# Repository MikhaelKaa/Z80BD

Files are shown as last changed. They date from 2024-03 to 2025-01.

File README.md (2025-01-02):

# Z80BD

## Описание

Этот проект представляет собой комплексное решение для аппаратной и программной отладки ZX Spectrum совместимых компьютеров. 

Первая версия прототипа собранного в январе 2024 года:

[{#Первый прототип}](/Proto_on_socket/README.md)

Текущая версия:

[{#Второй прототип}](/Proto_on_slot/)

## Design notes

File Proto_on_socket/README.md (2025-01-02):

# Z80BD

## Описание

Этот проект представляет собой комплексное решение для аппаратной и программной отладки компьютеров серии ZX Pentagon. Он включает в себя устройство для подмены ПЗУ микросхемой статической памяти, программатор на базе STM32 для удобной загрузки и выгрузки кода, а также дополнительные функции для расширения возможностей стандартного ZX Pentagon.

## Особенности

- **Подмена ПЗУ:** Устройство позволяет заменить стандартное ПЗУ на микросхему статической памяти, что облегчает процесс отладки и разработки.
- **Программатор STM32:** Встроенный программатор на базе STM32 обеспечивает простую загрузку и выгрузку кода, а также SRAM, что делает процесс разработки более гибким и доступным.
- **Чтение порта 0x7ffd:** Устройство расширяет возможности стандартного ZX Pentagon, добавляя функционал чтения порта 0x7ffd.
- **Совместимость с КЕШ-доработкой:** Устройство совместимо с популярной доработкой типа КЕШ, что позволяет использовать уже написанные для этого софты. Объем кеш памяти - 32768 байт.

## Начало работы

Для начала работы с устройством необходимо выполнить следующие шаги:

1. **Сборка устройства:** Следуйте инструкциям по сборке, предоставленным в разделе [Сборка устройства](#сборка-устройства).
2. **Прошивка программатора:** Загрузите последнюю версию прошивки для STM32, используя предоставленные инструменты.
3. **Подключение к ZX Pentagon:** Подключите устройство к ZX Pentagon согласно схеме подключения.
4. **Загрузка ПО:** Используйте программатор для загрузки необходимого ПО в статическую память.

## Сборка устройства

На данный момент сделан прототип.
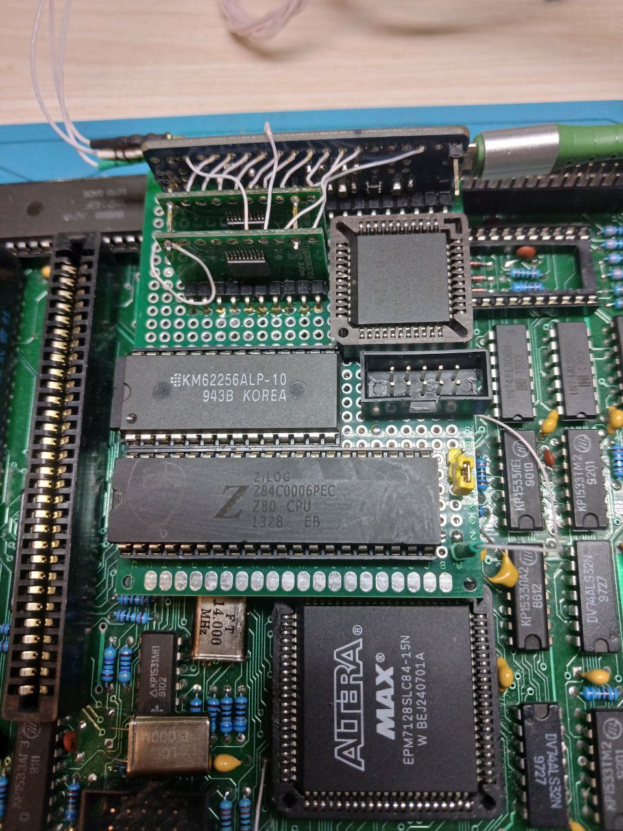
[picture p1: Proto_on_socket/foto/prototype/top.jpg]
top Установлен в PENTAGON-1024SL ver 2.2

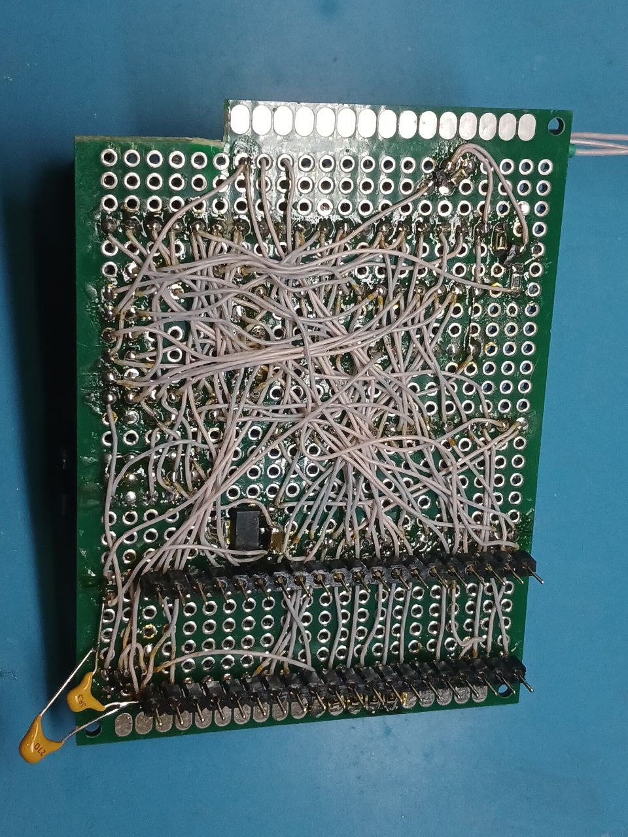
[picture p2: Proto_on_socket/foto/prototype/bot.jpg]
top Монтаж МГТФ


## Программное обеспечение

Програмное обеспечение находиться в стадии отладки и написания. Можно считать, что alpha версия есть.

## Схема подключения

В работе. В первой версии это будет плата-шляпа устнавливаемая в сокет процессора.

## Лицензия

Apache.

## Авторы

Михаил Каа

## Благодарности

Jeckas Nameless

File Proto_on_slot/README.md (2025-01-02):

# Z80BD

## Описание

Under constructions

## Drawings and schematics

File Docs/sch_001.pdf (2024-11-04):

# IO4 16 IO3 18 IO2 19 IO1 20 IO0 21

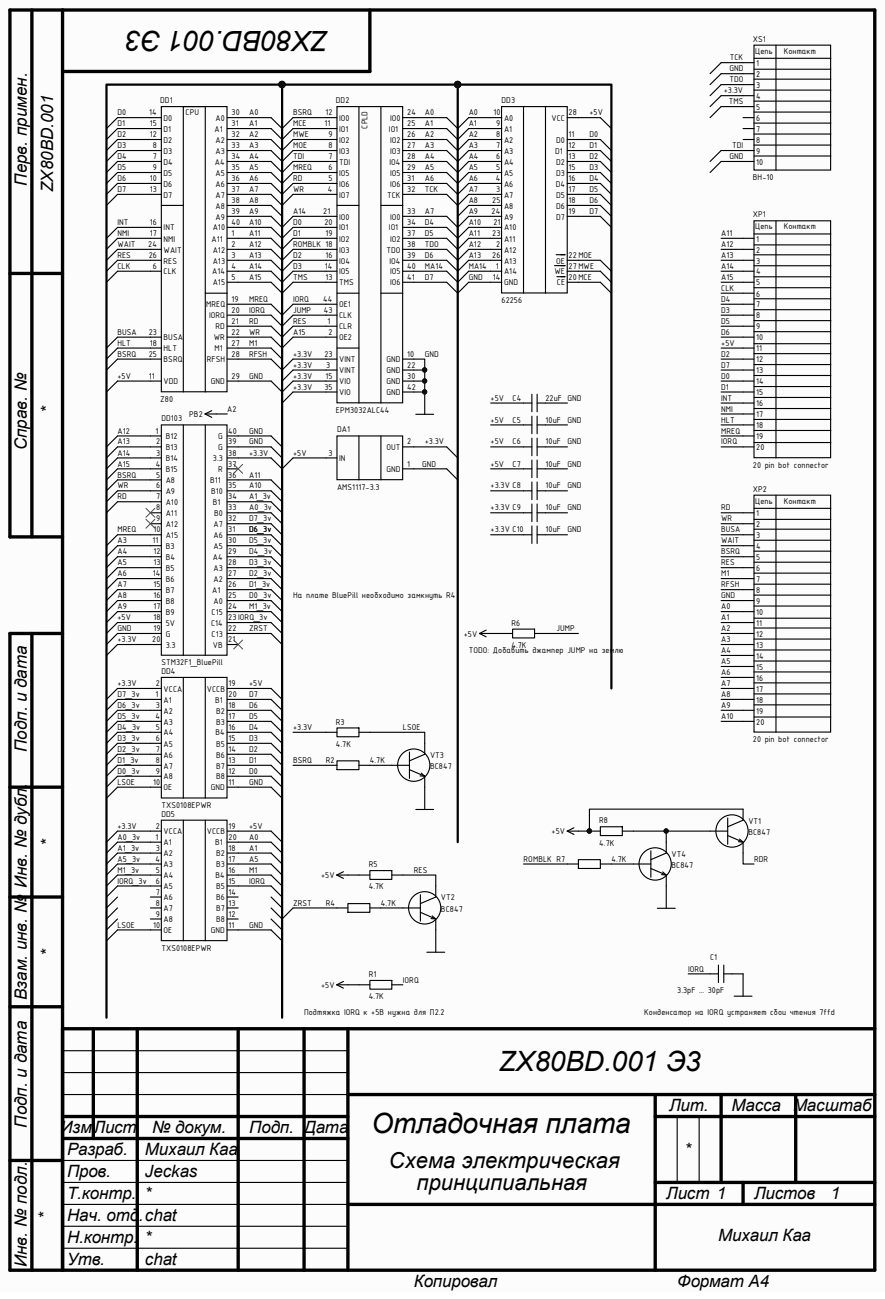
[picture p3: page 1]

Инв. № подл. Инв. № дубл. Подп. и дата Взам. инв. № Подп. и дата Перв. примен. Справ. №

На плате BluePill необходимо замкнуть R4

JUMP +5V
4.7K TODO: Добавить джампер JUMP на землю

Подтяжка IORQ к +5В нужна для П2.2

Конденсатор на IORQ устраняет сбои чтения 7ffd

Отладочная плата Схема электрическая принципиальная | Лит. | Масса Масштаб

Изм. | Лист | № докум. | Подп. Дата | | | *
Разраб. | | Михаил Каа
Пров. | Jeckas
Т.контр. | * | | | Лист 1 | Листов 1
Нач. отд.chat
Н.контр. | *
Утв. | chat

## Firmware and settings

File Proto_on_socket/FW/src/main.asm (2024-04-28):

    ; указываем ассемблеру, что целевая платформа - spectrum48, хотя это и не так, но похуй...
    device ZXSPECTRUM48
    ;SIZE 32768
begin:
    org 0x0000
    ; Запрещаем прерывания.
    di

    jp start

    org 0x0038 ; 56 
    di
    push af
    push bc
    push hl
    push de
    ;int programm
    ld a, 0b00000000
    out (0xfe), a
    ;end int programm
    pop de
    pop hl
    pop bc
    pop af
    ei
    reti

    org 0x100
start:
    
    ; Устанавливаем дно стека.
    ld sp, 16300 
    ;ei

    call cls
    call green_paper
    ld hl, msg_7ffd
    ld de, 0x0000
    call print_string

    ld  hl, target
    ld  de, 0x7000
    ld  bc, target_end-target
    ldir

    ld  hl, gamecode
    ld  de, 32768
    ld  bc, gamecode_end-gamecode
    ldir

    ;in a, (0x7b) ; выключить cash
    

    ;ld sp, 65535 
    ;jp 0x7000
    ; ld  hl, (23773 + 9)
    ; jp  (hl)
    ei
    
main_loop:

    ld a, 0b0000001
    ld bc, 0x7ffd
    out (c), a

    ld bc, 10
    call delay

    ld bc, 0x7ffd
    in a, (c)

    ld hl, temp
    ld (hl), a

    cp a, 0b0000001
    call z, print_ok
    ld hl, temp
    ld a, (hl)
    cp a, 0b0000001
    call nz, print_fail

    ld bc, 1200
    call delay

    ld a, 0b0000000
    ld bc, 0x7ffd
    out (c), a

    ld bc, 10
    call delay

    ld bc, 0x7ffd
    in a, (c)

    ld hl, temp
    ld (hl), a

    cp a, 0b0000000
    call z, print_ok
    ld hl, temp
    ld a, (hl)
    cp a, 0b0000000
    call nz, print_fail

    ld a, 0b00000111
    out (0xfe), a
    halt
    jp main_loop


print_ok:
    ld hl, msg_ok
    ld de, 0x0008
    call print_string
    ret

print_fail:
    ld hl, msg_fail
    ld de, 0x0008
    call print_string
    ret

cash_on:
    in a, (0xfb) ; включить cash
    ret

cash_off:
    in a, (0x7b) ; выключить cash
    ret

temp:
    db 0
msg_7ffd
    db "0x7ffd: ", 0
msg_ok:
    db "OK  ", 0
msg_fail:
    db "FAIL", 0
    display "msg_ok adr: ", /h, msg_ok
    

; Процедура задержки
; bc - время
delay:
    dec bc
    ld a, b
    or c
    jr nz, delay
    ret

    include "src/print.asm"

target:
    incbin "target.bin"
target_end:
gamecode:
    incbin "game_CODE.bin"
gamecode_end:

end:
    ; Выводим размер банарника.
    display "target size: ", /d, target_end - target
    display "code size: ", /d, end - begin
    SAVEBIN "build/out.bin", begin, 16384;  размер бинарного файла для прошивки ПЗУ\ОЗУ

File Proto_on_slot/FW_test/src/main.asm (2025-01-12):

    device ZXSPECTRUM48

begin:

mem_window_0_port EQU 0x0010
mem_window_1_port EQU 0x0011
mem_window_2_port EQU 0x0012
mem_window_3_port EQU 0x0014
system_port       EQU 0x0020

; uart_16550_port   EQU 0x00ef
uart_reg_0        EQU 0xf8ef
uart_reg_1        EQU 0xf9ef
uart_reg_2        EQU 0xfaef
uart_reg_3        EQU 0xfbef
uart_reg_4        EQU 0xfcef
uart_reg_5        EQU 0xfdef
uart_reg_6        EQU 0xfeef
uart_reg_7        EQU 0xffef

    org 0x0000
    ; Запрещаем прерывания.
    di

    org 0x0000
    ; Запрещаем прерывания.
    di

    ld	a, 0x0d
    ld	bc, 0xfcef
    out	(c),a

    ; ld	a, 0x06
    ld	a, 0x87
    ld	bc, 0xfaef
    out	(c),a

    ld	a, 0x83
    ld	bc, 0xfbef
    out	(c),a

    ld	a, 0x01
    ld	bc, 0xf8ef
    out	(c),a

    ld	a, 0x00
    ld	bc, 0xf9ef
    out	(c),a

    ld	a, 0x03
    ld	bc, 0xfbef
    out	(c),a

    ld	a, 0x00
    ld	bc, 0xf9ef
    out	(c),a

    ; ld	a, 0x2f
    ld	a, 0x0f
    ld bc, 0xfcef
    out	(c),a


    nop
    nop
    nop
    ; Z80 clock
    ld	a, 0x02
    ld	bc, system_port
    out	(c), a
    nop
    nop
    nop
    nop
    nop
    in	a, (c)
    nop
    nop
    nop
    nop
    nop


    ld e, 0
    ld a, 0x53; S
    ld	bc, 0xf8ef
    out	(c), a
    ld e, 0
    ld a, 0x0a
    ld	bc, 0xf8ef
    out	(c), a
    ld e, 0
    ld a, 0x0d
    ld	bc, 0xf8ef
    out	(c), a
    
main_loop:
    ld a, 0x55; U
    ld	bc, 0xf8ef
    out	(c), a

    ; ld a, 64
    ; ld bc, mem_window_3_port
    ; out (c), a
    ; ld (0xc001), 0x60
    ; ld a, (0xc001)
    ; ld	bc, 0xf8ef
    ; out	(c), a

    ld a, e
    ld bc, mem_window_1_port
    out (c), a
    ld hl, 0x4ff0
    ld (hl), 0x58 ; X
    ld a, (hl)
    ld	bc, 0xf8ef
    out	(c), a

    inc e

    ld	bc, 0x0ffe
delay:
    dec bc
    ld a, b
    or c
    jr nz, delay
    
    jr main_loop

end:
    ; Выводим размер банарника.
    display "code size: ", /d, end - begin
    SAVEBIN "./build/test.bin", begin, 16384;  размер бинарного файла для прошивки ПЗУ\ОЗУ

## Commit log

2024-02-20 >> init
    [Z80BD.PrjPCB, main.SchDoc]
2024-02-20 >> 62256 x2
    [Z80BD.PrjPCB, main.SchDoc]
2024-02-21 >> модели.
    [Z80BD.PrjPCB, main.SchDoc]
2024-02-21 >> Проверяю модельки компонентов.
    [Z80BD.PrjPCB, main.SchDoc]
2024-02-22 >> Схема начата, правка моделей.
    [main.SchDoc]
2024-02-22 >> Превью в gitignore
2024-02-22 >> sync
    [main.SchDoc]
2024-03-11 >> Сборка и проверка питания прототипа
    [main.SchDoc]
2024-03-12 >> Добавлен submodule с софтом для программатора.
2024-03-13 >> Работает, но нестабильно.
2024-03-14 >> Работает! Небыло контакта на старших адресных линиях.
    [main.SchDoc]
2024-03-15 >> Дешифрация для cash работает.
    [main.SchDoc]
2024-03-16 >> cash (32kb) по тесту 4.30 работоспособен.
    [Z80BD.PrjPCB, main.SchDoc]
2024-03-16 >> Добавлен джампер переключения кеш\пзу. +Шрифт
    [main.SchDoc]
2024-03-17 >> Конденсатор 30пФ на IORQ исправляет сбои чтения 7FFD.
    [main.SchDoc]
2024-03-19 >> print_char вроде работает.
2024-03-19 >> Добавлены тестовые проекты.
2024-03-19 >> Вывод строк. Без атрибутов и прочего.
2024-03-20 >> Сломалось.
2024-03-21 >> Рабочая версия с сменой экранов. 25 Гц
2024-03-22 >> Исправлен размер области для копирования в экран.
    [main.asm]
2024-03-24 >> print test
2024-03-24 >> 7ffd тест.
2024-03-24 >> Работает стабильно.
2024-03-25 >> README.md исправлены опечатки.
2024-03-31 >> добавлен М1 и эскиз компоновки ПП
    [main.SchDoc]
2024-04-15 >> Добавлен проект для сборки Си
2024-04-16 >> Добавлены ASM вставки
2024-04-16 >> Hello world (Си с асм вставками).
2024-04-21 >> Добавлен проект компорта.
    [comport.PrjPCB, main.SchDoc, pcb.PcbDoc]
2024-04-22 >> com port теперь на 3032
    [comport.PrjPCB, main.SchDoc, pcb.PcbDoc]
2024-04-28 >> added docs
    [comport.PrjPCB, main.SchDoc, pcb.PcbDoc]
2024-04-28 >> Изменена схема формирования RDR (Блокировка штатного ПЗУ)
    [main.SchDoc]
2024-04-29 >> Эксперименты с ком портом.
    [main.SchDoc, pcb.PcbDoc]
2024-05-01 >> Добавлена проверка бита 16650 о готовности данных.
2024-05-01 >> zx comport
    [comport.PrjPCB, main.SchDoc, pcb.PcbDoc]
2024-11-04 fix: На печатную плату добавлена линия с шириной слота
    [pcb.PcbDoc]
2024-11-23 fix: comport.PrjPCB
    [comport.PrjPCB, main.SchDoc]
2024-11-23 fix: Трассировка не удалась :)
2024-11-24 fix: переосмысление компоновки.
2024-11-25 fix: Другая компоновка
2024-11-25 fix: Вариант компоновки.
2024-11-25 add: Черновая трассировка.
    [main.SchDoc]
2024-11-25 trace: 50%. Компоновка не очень удачная.
2024-12-01 fix: Трассировка. Осталось землю и макетное поле.
    [comport.PrjPCB]
2024-12-04 fix: трассировка на критику
    [main.SchDoc]
2024-12-04 fix: teardrops, Спасибо Дмитрию за подсказку!
    [comport.PrjPCB]
2024-12-04 fix: исправления по результатам критики.
2024-12-04 add: файлы для производства
    [comport.PrjPCB, comport_bom.xls, main.SchDoc]
2024-12-08 fix: Удален побочный проект.
    [comport.PrjPCB, comport_bom.xls, main.SchDoc]
2024-12-20 add: Рыба для схемы с epm3128
    [epm3128.PrjPCB, main.SchDoc, pcb.PcbDoc]
2024-12-21 fix: Базовые компоненты на схеме.
    [epm3128.PrjPCB, main.SchDoc]
2024-12-21 add: Макетка для прототипов.
    [epm3128.PrjPCB, main.SchDoc, pcb.PcbDoc]
2024-12-21 fix: Номера выводов на макетке.
    [main.SchDoc, pcb.PcbDoc]
2024-12-21 add: На схему добавлен компорт без обвязки.
    [epm3128.PrjPCB, main.SchDoc]
2024-12-22 fix: Примерный габарит макетки.
    [main.SchDoc]
2024-12-29 fix: Схема макета.
    [main.SchDoc]
2024-12-30 fix: Схема
    [main.SchDoc]
2024-12-30 fix: Схема, распределение выводов по CPLD
    [main.SchDoc]
2024-12-30 add: Пустой проект для 3128
2024-12-30 fix: Макет менеджера памяти и тактирования CPU.
2024-12-31 add: Макет тестбенча. Не понятно как работать с inout.
2025-01-01 fix: частота клока в TB 24M, осталась проблема с x состоянием.
2025-01-01 fix: Чтение из портов менеджера памяти.
2025-01-01 add: эксперимент с делителем для 16550
2025-01-01 fix: Добавлен кварц для тактирования 16550.
    [main.SchDoc]
2025-01-01 fix: Добавлен регистр для управления частотой процессора.
2025-01-02 fix: Первый запуск, есть клок и активность на RD & MREQ
2025-01-02 fix: Изменения в структуре репозитария. Два проекта в отдельных директориях + макетка.
    [Z80BD.PrjPCB, epm3128.PrjPCB, main.SchDoc]
2025-01-03 fix: Правки в процессе сборки макета.
2025-01-04 fix: Заупуск, оно пытается читать ПЗУ
2025-01-04 add: макет теста для железа на asm
2025-01-06 fix: Первый стабильный запуск. Проблема в Z80.CLK от cpld - 3.3 Вольта это мало.
    [epm3128.PrjPCB, main.SchDoc]
2025-01-07 fix: 16550 работает нестабильно
    [main.SchDoc]
2025-01-12 fix: Простой тест ОЗУ. На первый взгляд оно работает.
    [main.SchDoc]
2025-01-12 err: сбоит переключение частоты клока
